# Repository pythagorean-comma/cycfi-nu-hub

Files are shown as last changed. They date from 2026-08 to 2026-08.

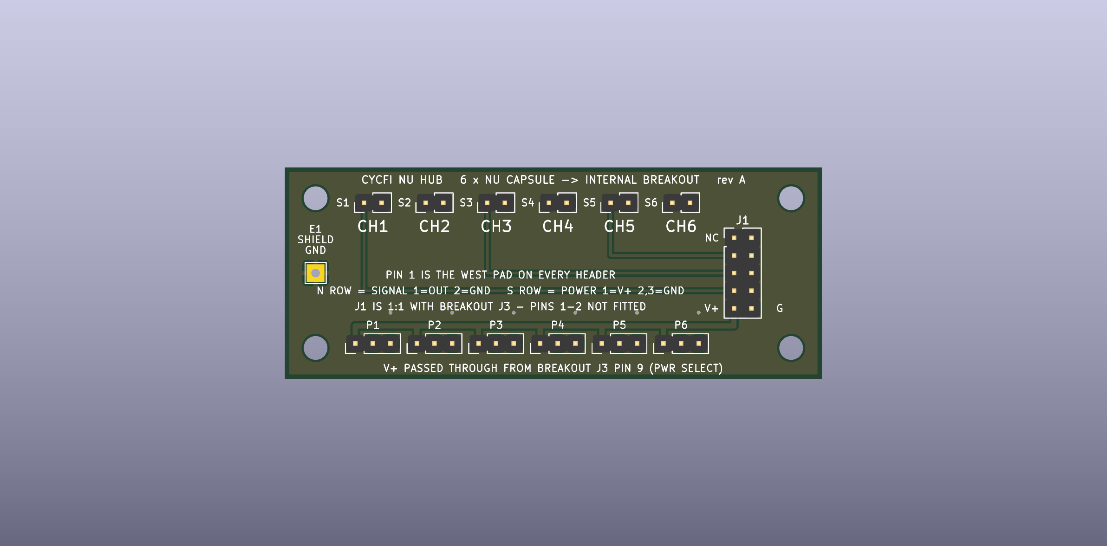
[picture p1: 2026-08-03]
fab/cycfi-nu-hub-top.png

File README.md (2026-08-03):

# Cycfi Nu Hub

A 6-channel hub board for wiring six individual **Cycfi Nu v2 capsules** into a v2.6
**Cycfi Internal Breakout** on channels 1–6.

Built against Cycfi's published Eagle sources at
<https://github.com/cycfi/nu>

61 × 24 mm, two layers, and **no components** — thirteen connectors, a
grounding pad and some copper. The capsules already decouple themselves, so
there is nothing left for this board to do but join things up correctly.

## Everything is generated

`design.py` is the single source of truth for the circuit. `gen_sch.py` draws
the schematic from it, `gen_pcb.py` places and routes the board from it, and
`verify.py` reads KiCad's own netlist back and compares it net by net.

```bash
./build.sh
```

That regenerates schematic *and* board, runs ERC, checks both against
`design.py`, runs DRC, and writes `fab/cycfi-nu-hub-pcbway.zip`, but **only
when DRC is clean**, so a board with known faults cannot reach a fab by
accident.

> **Anything changed in the KiCad GUI is destroyed by the next build.** Use the
> editor to inspect, measure and try things out; changes that should survive
> belong in the generator.

`design.py` also holds the two pin maps transcribed from Cycfi's schematics
and asserts the board against them at import, so a hub wired to the wrong
channels fails to load rather than fails on the bench.

## Requirements

**KiCad 10.x.** Install with `brew install --cask kicad`, or from
<https://www.kicad.org/download/>. The file formats written are version
specific: KiCad 9 will not open the generated schematic.

**No Python packages.** There is no virtual environment and no
`requirements.txt`, because there is nothing to install: the generators are
pure standard library. The one exception is `pcbnew`, which ships inside KiCad,
so `build.sh` runs `gen_pcb.py` under KiCad's own bundled interpreter and
everything else under `python3`. Set `PYTHON` to override which one.

`kicad.py` finds the installation. It checks `$KICAD_APP`, then
`/Applications/KiCad/KiCad.app`, then `~/Applications/KiCad/KiCad.app`, then
`kicad-cli` on `PATH`. If yours lives somewhere else:

```bash
export KICAD_APP=/path/to/KiCad.app
```

Run `python3 kicad.py` to see what it found.

## Where to read next

| | |
| --- | --- |
| [`docs/DESIGN.md`](docs/DESIGN.md) | What the board does and why, what must not be got wrong when wiring it, how it came out, and what is still open. **Start here.** |
| [`docs/CABLES.md`](docs/CABLES.md) | How to make the thirteen cables: parts, suppliers, position-by-position tables, and the continuity checks to run before anything is powered. |
| [`fab/ORDER.md`](fab/ORDER.md) | How to order it, including the four requirements that are invisible in the gerbers, and what to buy alongside it. It lives beside the gerbers rather than in `docs/` because `build.sh` copies it into the fabrication zip and `verify.py` checks the board against its figures. |
| [`docs/cycfi-sources.md`](docs/cycfi-sources.md) | What Cycfi's own files say, at a recorded commit, and how to re-extract it. Records, not specifications — where they and `docs/DESIGN.md` differ, `docs/DESIGN.md` is right. |

## Status

Generated, checked and clean: ERC 0, DRC 0 — **warnings included, not just
errors** — and the schematic matches `design.py` across 8 nets and 39 pin
connections. A fabrication package is written.

**Nothing has been made yet.** No board has been fabricated, no cable crimped
and nothing measured, so every claim in this repository comes from Cycfi's
sources and from the generators — not from a bench.

Two things to settle before ordering, both in the last section of
[`docs/DESIGN.md`](docs/DESIGN.md): Cycfi publish sources for breakout **v2.5** and this
targets **v2.6**, which is three continuity readings on J3 to confirm; and the
breakout's `PWR SELECT` jumper decides what voltage six capsules will see.

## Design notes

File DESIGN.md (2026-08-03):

# The Cycfi Nu hub

Six individual **Cycfi Nu v2 capsules** onto channels 1–6 of a v2.6 **Cycfi
Internal Breakout**, so that wiring them up is thirteen crimped connectors
instead of a bundle of flying leads into a connector that was designed for a
pre-assembled Nu Multi.

The board is 61 × 24 mm, two layers, and **carries no components at all**. It
is thirteen connectors, one solder pad, four holes and some copper. That is
not minimalism for its own sake — see [No components](#no-components).

---

## What this replaces

Cycfi's breakout expects a **Nu Multi**: a pre-built assembly of capsules that
arrives on one 2×5 ribbon. If you have six separate capsules instead, you have
twelve connectors to get to that one 2×5, and each capsule contributes two of
them, at opposite ends of its own PCB.

    six capsules                    this board              breakout
    ------------                    ----------              --------
    H2  3-pin power  -- cable -->  P1..P6                \
    H1  2-pin signal -- cable -->  S1..S6                 >-- J1 --> J3
                                                         /   2x5

## Verified, not assumed

Everything about the two mating connectors was read out of Cycfi's Eagle
sources, at a recorded commit, and is transcribed in
[`docs/cycfi-sources.md`](docs/cycfi-sources.md). The three facts the board
depends on:

1. **The capsule has two connectors, not one.** A 3-pin 2.00 mm header for
   power at one end of its PCB, pin 1 = V+ through a reverse-polarity
   Schottky — and separately a 2-pin 2.00 mm header for signal at the other
   end, pin 1 = OUT through a 10 µF coupling cap.
2. **Pins 2 *and* 3 of the power header are ground.** The capsule commits two
   of its three power positions to it.
3. **The capsule decouples itself**: 100 nF and 4.7 µF across its own supply,
   on the capsule, at the pin.

These are not comments. `design.py` holds them as `CAPSULE` and
`BREAKOUT_J3`, and `Design.check_against_cycfi()` asserts the whole board's
pin map against them at import — so a hub wired to the wrong channels fails
to load rather than fails on the bench.

That check exists because nothing else would catch it. A wrong-but-consistent
pin map is still consistent: ERC passes, the netlist comparison passes, DRC
passes, and the first symptom is six strings coming out of the wrong outputs.

## The pin map — this *is* the design

`J1` is wired **one-to-one with breakout J3**. Position *n* on the cable goes
to position *n* at both ends; nothing crosses inside it.

| J1 / J3 pin | Net | Goes to |
| --- | --- | --- |
| 1 | *CH7* | **not fitted** |
| 2 | *CH8* | **not fitted** |
| 3 | CH5 | S5 pin 1 |
| 4 | CH6 | S6 pin 1 |
| 5 | CH3 | S3 pin 1 |
| 6 | CH4 | S4 pin 1 |
| 7 | CH1 | S1 pin 1 |
| 8 | CH2 | S2 pin 1 |
| 9 | V+ | P1–P6 pin 1 |
| 10 | GND | everything |

And at the capsule end, each channel *n*:

| Header | Pin | Net | Capsule |
| --- | --- | --- | --- |
| `Pn` (1×3) | 1 | V+ | H2 pin 1 |
| | 2, 3 | GND | H2 pins 2, 3 |
| `Sn` (1×2) | 1 | CH*n* | H1 pin 1 |
| | 2 | GND | H1 pin 2 |

**Pin 1 is the west-most pad on every header on the board**, including the
2×5. One rule, printed on the silkscreen, and asserted in
`gen_pcb.check_placement()` against the real pad coordinates rather than
trusted to a rotation convention.

## What must not be got wrong

### Leave positions 1 and 2 out of the cable

They are CH7 and CH8, and those nets are **shared with J4 pins 7–8** — the
breakout's second Nu Multi input. Driving them from here contends with
anything plugged in there.

### Reversal is harmless, and that is why

A 2×5 rotated in its own plane maps pin *n* to pin **11 − *n***. So a cable
plugged in backwards puts the two *empty* positions onto pins 10 and 9 — GND
and V+ — and the hub receives no supply at all. The capsules stay dark, the
hub's own V+ and GND land on CH8 and CH7 where nothing is driving them hard,
and nothing is damaged.

This is worth stating because it is the reason the board has a **plain,
unshrouded** 2×5. Shrouding at 2.00 mm means committing to a keyed family —
JST PHD or Hirose DF11 are the stock options whose pin numbering matches
Cycfi's — and that puts a *different crimp terminal at each end of the same
cable*, since the breakout end still has to mate with a plain header. Paying
that to protect against a failure whose entire consequence is "it does not
turn on" is a bad trade.

If the cable ever works loose under vibration, the answer is a tie or a dab of
hot glue, not a respin.

### The two 2.00 mm systems are not interchangeable

Everything here mates with **2.00 mm female crimp housings on 0.50 mm square
posts**. Pick one connector family and stay in it for the whole loom, so there
is one terminal and one tool. This is not the same as JST PH, which is also
2.00 mm and will not fit.

## No components

`design.py` states this as `NO_COMPONENTS` and enforces it in
`Design.check_no_components()`, which rejects any part that is not a
connector, a mounting hole or the grounding pad.

The previous revision of this board had six decoupling capacitors on it. They
were doing nothing, and the reason is worth keeping: **every Nu capsule
already carries 100 nF and 4.7 µF across its own supply pins, at the pin, on
the capsule PCB.** A capacitor on the hub sits at the far end of a cable from
every load it could serve. It is not decoupling; it is a part that measures as
wire.

There is nothing to protect either. Pin 1 of the capsule's power header goes
through a Schottky *on the capsule*, so reverse polarity is handled where it
matters, and — per above — a reversed 2×5 delivers no supply rather than the
wrong one.

So the board permits, permanently: connectors, mounting holes, one grounding
pad. If a resistor or capacitor appears in the parts list, either the circuit
has genuinely changed or something was added on instinct, and the build says
so.

## Grounding

GND is poured on **both** layers. On a two-layer board that is mostly air the
copper is free, and what it buys is a return directly under every signal trace
and a reference plane between the six of them. Against a Nu's low-impedance
op-amp output that is worth little — but it is worth nothing against it
either, and it costs the same to fabricate. Six stitching vias tie the pours
together, on top of the nineteen through-hole GND pads that already do.

**E1** is a 2.0 × 2.0 mm pad on a 1.0 mm hole, on GND, for a bridge earth or a
cavity-shielding tail. It is optional. Fitting the pad does not commit you to
using it, and in an all-active instrument some builders deliberately leave the
bridge floating — that is the path that puts the player at mains potential if
something upstream fails. Use it for foil and decide about the bridge
separately.

The objection to landing bridge earth here is that it makes the hub the ground
meeting point, so string-borne hum shares the single GND wire in the cable
with six signal returns. At microamps through tens of milliohms that is
nanovolts. It is not a real mechanism at these levels.

**The four mounting holes are unplated and off the ground net**, deliberately.
A hub screwed into a shielded cavity with metal screws and plated holes would
bond the audio ground to the foil through the mounting hardware, in parallel
with the cable — a second ground path, which is the loop the single-point pad
exists to avoid.

## How the board came out

A 61 × 24 mm strip. Signal headers along the north edge, power headers along
the south, the 2×5 at the east end, six channel columns on a 7 mm pitch with
**CH1 (low E) at the west**, so reading the board left to right reads the
strings low to high. The two cable bundles leave on opposite edges.

`verify.check_string_order()` reads the string order back off the built
copper. Nothing electrical would notice it being wrong.

### The one hard part: reaching the far row of J1

The 2×5's pads are 1.35 mm on a 2.00 mm pitch. The clear gap between two of
them is **0.65 mm**, and a 0.30 mm track with 0.25 mm either side needs
**0.80 mm**. Nothing can be routed between the pads of a 2.00 mm header, so
the far row cannot be reached from the near side at all. `rules.py` asserts
this rather than leaving it as folklore, because the whole layout is shaped by
it.

So the near row — J1's odd pins, CH5/CH3/CH1 — is reached directly from the
west on F.Cu, and the far row — even pins, CH6/CH4/CH2 — goes **north of the
signal headers on B.Cu, east above the whole row, down the outside of the
connector, and back in from the east**, where nothing is in the way. Three
concentric L-shaped paths around the north-east corner.

Two placement decisions make that fan-in planar, and both are the opposite of
what looks natural:

- **CH1 at the west, J1 at the east.** The connector puts CH1/CH2 on its
  southern pair and CH5/CH6 on its northern one, so a channel's target *y*
  falls as its number falls. With CH1 furthest from the connector, the
  westmost channel wants the deepest lane, and every drop clears every lane
  already laid. Mirror the board and all three cross.
- **The detour goes north of the signal headers, not between them and J1.**
  Put the lanes south of the header row and the drops cross them; put them
  north and the headers sit on the boundary, where the three paths nest.

I got the second one wrong twice before checking it as a planarity problem
rather than by eye.

### Everything else

- The power row has no gaps: six 1×3 footprints on a 7 mm pitch leave 0.78 mm
  between silk outlines, which is why nothing crosses it and why the power
  designators are printed above the row instead of beside it.
- The two eastern mounting holes set the board width. Their courtyards are
  6 mm across because they have to clear a screw head, and they have to sit
  clear of the three descents to J1's far row.
- V+ runs as one bus on F.Cu between J1's bottom pair and the power row.
  0.60 mm, which is not about current — six capsules draw single-figure
  milliamps between them — but about keeping the run stiff and inspectable.
- The build gates on DRC **warnings as well as errors**. It did not at first,
  and asking only for errors hid twenty-seven violations of this project's own
  rules: every legend was under the minimum silk text height written into the
  `.kicad_pro`, and six designators overlapped their own footprint outlines.
  None of it would have scrapped a board and all of it would have reached one.
  `rules.MIN_SILK_TEXT` is now the single place that height is declared, so
  the generator and the checker cannot disagree about it again.

## Still open

**The breakout revision.** Cycfi's published sources are silkscreened
*INTERNAL BREAKOUT V2.5* and this hub targets **v2.6**. Nothing the hub
touches is known to have changed, and Cycfi have not published 2.6 sources —
but it has not been *checked*, and it is one continuity test to settle. Before
building the cable, meter J3 on the actual breakout: **pin 9 to V+, pin 10 to
ground, pin 7 to channel 1.** If those three are right, the whole table is.

**Which rail the PWR SELECT jumper is on.** J14 on the breakout selects
whether V+ is the unregulated input or the LP2985 output. The hub passes
through whatever it is, so the board does not care — but the capsules do.
Confirm the jumper is where you want it before six capsules see it.

**Nothing has been fabricated yet.** No board has been made, no cable crimped
and nothing measured. Every claim here is from the sources and the generators.

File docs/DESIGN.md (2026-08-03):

# The Cycfi Nu hub

Six individual **Cycfi Nu v2 capsules** onto channels 1–6 of a v2.6 **Cycfi
Internal Breakout**, so that wiring them up is thirteen crimped connectors
instead of a bundle of flying leads into a connector that was designed for a
pre-assembled Nu Multi.

The board is 61 × 24 mm, two layers, and **carries no components at all**. It
is thirteen connectors, one solder pad, four holes and some copper. That is
not minimalism for its own sake — see [No components](#no-components).

---

## What this replaces

Cycfi's breakout expects a **Nu Multi**: a pre-built assembly of capsules that
arrives on one 2×5 ribbon. If you have six separate capsules instead, you have
twelve connectors to get to that one 2×5, and each capsule contributes two of
them, at opposite ends of its own PCB.

    six capsules                    this board              breakout
    ------------                    ----------              --------
    H2  3-pin power  -- cable -->  P1..P6                \
    H1  2-pin signal -- cable -->  S1..S6                 >-- J1 --> J3
                                                         /   2x5

## Verified, not assumed

Everything about the two mating connectors was read out of Cycfi's Eagle
sources, at a recorded commit, and is transcribed in
[`cycfi-sources.md`](cycfi-sources.md). The three facts the board
depends on:

1. **The capsule has two connectors, not one.** A 3-pin 2.00 mm header for
   power at one end of its PCB, pin 1 = V+ through a reverse-polarity
   Schottky — and separately a 2-pin 2.00 mm header for signal at the other
   end, pin 1 = OUT through a 10 µF coupling cap.
2. **Pins 2 *and* 3 of the power header are ground.** The capsule commits two
   of its three power positions to it.
3. **The capsule decouples itself**: 100 nF and 4.7 µF across its own supply,
   on the capsule, at the pin.

These are not comments. `design.py` holds them as `CAPSULE` and
`BREAKOUT_J3`, and `Design.check_against_cycfi()` asserts the whole board's
pin map against them at import — so a hub wired to the wrong channels fails
to load rather than fails on the bench.

That check exists because nothing else would catch it. A wrong-but-consistent
pin map is still consistent: ERC passes, the netlist comparison passes, DRC
passes, and the first symptom is six strings coming out of the wrong outputs.

## The pin map — this *is* the design

`J1` is wired **one-to-one with breakout J3**. Position *n* on the cable goes
to position *n* at both ends; nothing crosses inside it.

| J1 / J3 pin | Net | Goes to |
| --- | --- | --- |
| 1 | *CH7* | **not fitted** |
| 2 | *CH8* | **not fitted** |
| 3 | CH5 | S5 pin 1 |
| 4 | CH6 | S6 pin 1 |
| 5 | CH3 | S3 pin 1 |
| 6 | CH4 | S4 pin 1 |
| 7 | CH1 | S1 pin 1 |
| 8 | CH2 | S2 pin 1 |
| 9 | V+ | P1–P6 pin 1 |
| 10 | GND | everything |

And at the capsule end, each channel *n*:

| Header | Pin | Net | Capsule |
| --- | --- | --- | --- |
| `Pn` (1×3) | 1 | V+ | H2 pin 1 |
| | 2, 3 | GND | H2 pins 2, 3 |
| `Sn` (1×2) | 1 | CH*n* | H1 pin 1 |
| | 2 | GND | H1 pin 2 |

**Pin 1 is the west-most pad on every header on the board**, including the
2×5. One rule, printed on the silkscreen, and asserted in
`gen_pcb.check_placement()` against the real pad coordinates rather than
trusted to a rotation convention.

## What must not be got wrong

### Leave positions 1 and 2 out of the cable

They are CH7 and CH8, and those nets are **shared with J4 pins 7–8** — the
breakout's second Nu Multi input. Driving them from here contends with
anything plugged in there.

### Reversal is harmless, and that is why

A 2×5 rotated in its own plane maps pin *n* to pin **11 − *n***. So a cable
plugged in backwards puts the two *empty* positions onto pins 10 and 9 — GND
and V+ — and the hub receives no supply at all. The capsules stay dark, the
hub's own V+ and GND land on CH8 and CH7 where nothing is driving them hard,
and nothing is damaged.

This is worth stating because it is the reason the board has a **plain,
unshrouded** 2×5. Shrouding at 2.00 mm means committing to a keyed family —
JST PHD or Hirose DF11 are the stock options whose pin numbering matches
Cycfi's — and that puts a *different crimp terminal at each end of the same
cable*, since the breakout end still has to mate with a plain header. Paying
that to protect against a failure whose entire consequence is "it does not
turn on" is a bad trade.

If the cable ever works loose under vibration, the answer is a tie or a dab of
hot glue, not a respin.

### The two 2.00 mm systems are not interchangeable

Everything here mates with **2.00 mm female crimp housings on 0.50 mm square
posts**. Pick one connector family and stay in it for the whole loom, so there
is one terminal and one tool. This is not the same as JST PH, which is also
2.00 mm and will not fit.

## No components

`design.py` states this as `NO_COMPONENTS` and enforces it in
`Design.check_no_components()`, which rejects any part that is not a
connector, a mounting hole or the grounding pad.

The previous revision of this board had six decoupling capacitors on it. They
were doing nothing, and the reason is worth keeping: **every Nu capsule
already carries 100 nF and 4.7 µF across its own supply pins, at the pin, on
the capsule PCB.** A capacitor on the hub sits at the far end of a cable from
every load it could serve. It is not decoupling; it is a part that measures as
wire.

There is nothing to protect either. Pin 1 of the capsule's power header goes
through a Schottky *on the capsule*, so reverse polarity is handled where it
matters, and — per above — a reversed 2×5 delivers no supply rather than the
wrong one.

So the board permits, permanently: connectors, mounting holes, one grounding
pad. If a resistor or capacitor appears in the parts list, either the circuit
has genuinely changed or something was added on instinct, and the build says
so.

## Grounding

GND is poured on **both** layers. On a two-layer board that is mostly air the
copper is free, and what it buys is a return directly under every signal trace
and a reference plane between the six of them. Against a Nu's low-impedance
op-amp output that is worth little — but it is worth nothing against it
either, and it costs the same to fabricate. Six stitching vias tie the pours
together, on top of the nineteen through-hole GND pads that already do.

### E1

A 2.0 × 2.0 mm pad on a 1.0 mm hole, on GND, silkscreened SHIELD / GND.

**It is not a circuit feature.** GND is already poured across both layers, so
E1 adds no connection — it is simply the one place where the mask is open and
the pad is big enough to solder a wire to. That is its whole point: without
it, somebody eventually abrades the pour or hangs a tail off an occupied
connector pin. It costs one hole and no board area, since the west margin it
sits in is set by the mounting holes and would be empty anyway.

It has three jobs, and only the first is designed in.

**The trunk cable's screen.** [`CABLES.md`](CABLES.md) specifies screened cable
for the hub → breakout run with the screen grounded **at one end only**, so it
cannot become a second ground path in parallel with the GND conductor in
position 10. E1 is that end. Use screened cable and the pad stops being
optional — there is nowhere else for the drain to go.

**Cavity foil.** Shielding does nothing unless it is tied to circuit ground,
and left floating it can couple slightly worse than none. But foil carries
only displacement currents, so it can be grounded anywhere on the system —
the hub is convenient, not required.

**A bridge earth, distantly.** Weaker here than the convention suggests. The
mechanism it defends against — the player's body coupling mains hum into a
high-impedance circuit — is largely handled already by every Nu output being
an op-amp behind a 10 µF capacitor into low-impedance cabling. Against that,
it is the connection that puts the player at circuit ground through the
strings, which in an upstream fault is a path toward mains potential, and it
conventionally belongs at the system's main ground point rather than on a leaf
board at the far end of a cable. Fitting the pad does not commit you to using
it for this, and the silkscreen deliberately does not say BRIDGE.

One objection that does *not* stand up: that landing a tail here makes the hub
a ground meeting point, so its return shares the single GND wire in the cable
with six signal returns. At microamps through tens of milliohms that is
nanovolts. It is not a real mechanism at these levels.

**The four mounting holes are unplated and off the ground net**, deliberately.
A hub screwed into a shielded cavity with metal screws and plated holes would
bond the audio ground to the foil through the mounting hardware, in parallel
with the cable — a second ground path, which is the loop the single-point pad
exists to avoid.

## How the board came out

A 61 × 24 mm strip. Signal headers along the north edge, power headers along
the south, the 2×5 at the east end, six channel columns on a 7 mm pitch with
**CH1 (low E) at the west**, so reading the board left to right reads the
strings low to high. The two cable bundles leave on opposite edges.

`verify.check_string_order()` reads the string order back off the built
copper. Nothing electrical would notice it being wrong.

### The one hard part: reaching the far row of J1

The 2×5's pads are 1.35 mm on a 2.00 mm pitch. The clear gap between two of
them is **0.65 mm**, and a 0.30 mm track with 0.25 mm either side needs
**0.80 mm**. Nothing can be routed between the pads of a 2.00 mm header, so
the far row cannot be reached from the near side at all. `rules.py` asserts
this rather than leaving it as folklore, because the whole layout is shaped by
it.

So the near row — J1's odd pins, CH5/CH3/CH1 — is reached directly from the
west on F.Cu, and the far row — even pins, CH6/CH4/CH2 — goes **north of the
signal headers on B.Cu, east above the whole row, down the outside of the
connector, and back in from the east**, where nothing is in the way. Three
concentric L-shaped paths around the north-east corner.

Two placement decisions make that fan-in planar, and both are the opposite of
what looks natural:

- **CH1 at the west, J1 at the east.** The connector puts CH1/CH2 on its
  southern pair and CH5/CH6 on its northern one, so a channel's target *y*
  falls as its number falls. With CH1 furthest from the connector, the
  westmost channel wants the deepest lane, and every drop clears every lane
  already laid. Mirror the board and all three cross.
- **The detour goes north of the signal headers, not between them and J1.**
  Put the lanes south of the header row and the drops cross them; put them
  north and the headers sit on the boundary, where the three paths nest.

I got the second one wrong twice before checking it as a planarity problem
rather than by eye.

### Everything else

- The power row has no gaps: six 1×3 footprints on a 7 mm pitch leave 0.78 mm
  between silk outlines, which is why nothing crosses it and why the power
  designators are printed above the row instead of beside it.
- The two eastern mounting holes set the board width. Their courtyards are
  6 mm across because they have to clear a screw head, and they have to sit
  clear of the three descents to J1's far row.
- V+ runs as one bus on F.Cu between J1's bottom pair and the power row.
  0.60 mm, which is not about current — six capsules draw single-figure
  milliamps between them — but about keeping the run stiff and inspectable.
- The build gates on DRC **warnings as well as errors**. It did not at first,
  and asking only for errors hid twenty-seven violations of this project's own
  rules: every legend was under the minimum silk text height written into the
  `.kicad_pro`, and six designators overlapped their own footprint outlines.
  None of it would have scrapped a board and all of it would have reached one.
  `rules.MIN_SILK_TEXT` is now the single place that height is declared, so
  the generator and the checker cannot disagree about it again.

## Still open

**The breakout revision — mostly resolved.** Cycfi's published *sources* are
silkscreened *INTERNAL BREAKOUT V2.5* and this hub targets **v2.6**. They have
not published 2.6 Eagle files, but they do publish a
[v2.6.1 datasheet](https://www.cycfi.com/assets/Internal-Breakout-2.6.pdf),
and its "Nu Multi Inputs Ch 1-8" diagram gives the two rows as

    Ch8  Ch6  Ch4  Ch2  Gnd
    Ch7  Ch5  Ch3  Ch1  10v

which pairs **exactly** as the v2.5 sources do — CH7/CH8, CH5/CH6, CH3/CH4,
CH1/CH2, supply/ground. The pin map this board is built on survives the
revision.

What a printed pin map cannot tell you is which physical end of the connector
is position 1, and the v2.6 board is a different shape from the v2.5 one
(Cycfi list it as 27 × 38 mm against the 50 × 35 mm in the Eagle files), so
the connector may well sit differently. That is still one meter reading to
settle: **pin 9 to the supply rail, pin 10 to ground, pin 7 to channel 1.**
[`CABLES.md`](CABLES.md) has it as a numbered step.

**What voltage the capsules will see.** On v2.5 the Nu Multi input's supply
pin is a net called V+, fed from `J14`, a jumper silkscreened `PWR SELECT`
that chooses between the unregulated input and the LP2985 output. On v2.6.1
the same pin is labelled simply **10V**. The hub passes through whatever it
is, so the board does not care — but six capsules do. Measure it at the hub
with no capsules connected before fitting any.

**Nothing has been fabricated yet.** No board has been made, no cable crimped
and nothing measured. Every claim here is from the sources and the generators.

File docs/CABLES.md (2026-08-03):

# Making the cables

Thirteen cables connect six Nu capsules to the hub, and the hub to the
Internal Breakout. None of them is difficult. One of them — the capsule power
cable — has a way of going wrong that shorts the supply, and it is the exact
mistake that Cycfi's own cable guide will lead you into if you follow it
literally. That is [warning 1](#1-position-1-is-not-ground) below, and it is
the reason this document exists rather than a link.

Read Cycfi's guide for **technique**:
<https://www.cycfi.com/how-to-make-and-repair-pin-header-cables/>. It is
better than anything written here on how to actually hold the tool. Read this
for **which wire goes where**.

---

## What you are building

| # | Cable | Ends | Positions used | Qty |
| --- | --- | --- | --- | --- |
| 1 | Capsule power | 3-way ↔ 3-way | 3 of 3 | 6 |
| 2 | Capsule signal | 2-way ↔ 2-way | 2 of 2 | 6 |
| 3 | Hub → breakout | 2×5 ↔ 2×5 | **8 of 10** | 1 |

Two cables per capsule and not one, because the capsule has two connectors: a
3-pin power header at one end of its PCB and a 2-pin signal header at the
other. The hub mirrors that — `P1`–`P6` along its south edge, `S1`–`S6` along
its north edge, same channel in the same column.

---

## Two warnings before you buy anything

### 1. Position 1 is not ground

Cycfi's guide says:

> "Make sure you insert all GND wires (black) into position 1, indicated by a
> small molded triangle in the crimp housing"

**That is for a different cable. Do not do it here.** On the Nu capsule's own
connectors, read out of Cycfi's Eagle schematic:

| Capsule connector | Position 1 is |
| --- | --- |
| H2, 3-pin power | **V+**, through a Schottky diode on the capsule |
| H1, 2-pin signal | **OUT**, through the 10 µF coupling capacitor |

Ground is on positions 2 and 3 of the power header, and position 2 of the
signal header. The hub mirrors the capsule exactly, so the same is true at
both ends of every capsule cable.

Get this backwards on a power cable and you connect the supply rail to the
capsule's ground: the Schottky blocks the reverse feed so the capsule never
powers up, and V+ sits shorted to ground through the capsule's ground pour.
The breakout's regulator will current-limit or shut down. Nothing here is
subtle enough to survive by luck — **check the triangle against the tables
below before you insert a single contact.**

The molded-triangle convention itself is right and worth using: the triangle
marks position 1 on the housing. On the hub, **position 1 is always the
west-most pad**, which is printed on the silkscreen.

### 2. Two positions on the 2×5 stay empty

Positions **1 and 2** of the hub → breakout cable are not crimped, at either
end. They are the breakout's CH7 and CH8, and those two nets are shared with
J4 pins 7–8 — the second Nu Multi input. Filling them would contend with
anything plugged in there.

Leaving them empty is also what makes a reversed cable harmless: a 2×5
rotated in its own plane maps position *n* to position 11 − *n*, so the two
empty positions land on V+ and GND and the hub receives no supply at all.
A backwards cable is a dead cable, not a dead capsule.

---

## Tools

| Tool | Notes |
| --- | --- |
| **Engineer PA-09 crimping pliers** | Cycfi's choice, and the right one. Four dies: 1.0 / 1.4 / 1.6 / 1.9 mm. [Amazon](https://www.amazon.com/ENGINEER-AWG32-AWG20-Connectors-Oil-Resistant-PA-09/dp/B002AVVO7K) · [The Pi Hut](https://thepihut.com/products/universal-micro-crimping-pliers-1-0-to-1-9mm-size-contacts) · [TME](https://www.tme.com/us/en-us/details/fut.pa-09/crimping-tools-for-terminals/engineer/pa-09/) |
| Wire strippers | Something that will do 28–30 AWG cleanly |
| Flush cutters | |
| Fine tweezers | For inserting contacts and for extraction during repair |
| **Multimeter with continuity beep** | Not optional. See [Verify](#verify-before-you-plug-anything-in). |
| Heat gun or lighter | |

**On the die size.** Cycfi write *"Use the 1/4″ cavity size for the 2 mm crimp
terminals."* The PA-09 has no 1/4-inch die — its four dies are metric, marked
1.0, 1.4, 1.6 and 1.9 mm — so read that as the **1.4 mm** die. Do not take my
word for it either: crimp one contact, look at it under magnification, and
pull on the wire hard. The wire should not come out and the insulation grip
should be closed on the jacket, not on bare conductor. Adjust a die size
either way if it is not right. You will make 76 of these; spend the first
three getting the setting right.

If you go the Hirose DF11 route for the 2×5 (below), Hirose's own hand tool is
[DF11-TA2428HC](https://www.newark.com/hirose-hrs/df11-ta2428hc/hand-crimp-tool-28-24awg-skt-contact/dp/49P5012).
It is far more expensive than the PA-09 and only worth it if you are making
these regularly.

---

## Parts

### Single-row housings and contacts — capsule cables

These are Hirose's 2.00 mm single-row crimp system, the same parts Cycfi
specify in their guide.

| Part | What | Qty needed | Where |
| --- | --- | --- | --- |
| **A4B-3S-2C** | 3-way housing, 2.00 mm | 12 | [DigiKey H2012-ND](https://www.digikey.com/en/products/detail/hirose-electric-co-ltd/A4B-3S-2C/141219) · [RS 7644761](https://uk.rs-online.com/web/p/wire-housings-plugs/7644761) |
| **A4B-2S-2C** | 2-way housing, 2.00 mm | 12 | [DigiKey 141216](https://www.digikey.com/en/products/detail/hirose-electric-co-ltd/A4B-2S-2C/141216) · [Mouser](https://www.mouser.com/ProductDetail/Hirose-Connector/A4B-2S-2C) |
| **A3B-2630SCC** | Crimp socket, gold, 26–30 AWG | 60 → **buy 90** | [Mouser](https://www.mouser.com/ProductDetail/Hirose-Connector/A3B-2630SCC) |

Twelve of each housing, not six: every cable has one at each end.

### The 2×5 — the one part I could not verify

**Both ends of this cable are the same interface, and that is deliberate.** The
hub's `J1` and the breakout's `J3` are both plain, unshrouded 2×5 headers on a
2.00 mm grid with 0.5 mm square posts — Cycfi's is the `2X5` package from their
`headers(2mm)` Eagle library, the hub's is KiCad's
`PinHeader_2x05_P2.00mm_Vertical`. The PCB hole sizes differ slightly, 0.75 mm
against 0.80 mm, but that is the board, not the pin: the same commodity header
strip fits both, and both number their pins in pairs across the rows, which is
what lets the cable be wired one-to-one.

Three consequences, and they are the whole reason to keep it that way:

- **One test-fit qualifies both ends.** Whatever you prove on the hub is
  equally true of the breakout, because it is the same part.
- **Whichever housing wins is used at both ends.** One housing, one contact,
  one crimp setting for the trunk, and the two ends are interchangeable.
- **If the first choice fails, nothing is stranded** except the sample. Swap
  routes and you are still symmetric.

It is tempting to fix this by fitting a keyed, shrouded connector at the hub —
a Hirose `DF11-10DP-2DSA` in place of the plain header. Don't. It buys
certainty about the end that was never in doubt, still leaves the breakout end
to be tested, and pays for it by making the cable asymmetric and committing
the hub to one connector family for good. The retention it adds is
half a fix that a cable tie does properly at both ends for nothing.

What you need, then, is a 10-way (2×5) socket housing that fits bare 0.5 mm
square posts. **I could not confirm a specific part for this from the
manufacturers' documentation, and I am not going to pretend otherwise.** Two
routes, and whichever you pick, **buy one housing and a few contacts first and
test-fit them on the hub** — that sample decides the whole trunk, so it is
worth having in your hand before the rest of the order goes in. Test on the
hub rather than the breakout: same interface, and you are not levering an
unproven connector onto Cycfi's board.

| Route | Parts | Trade-off |
| --- | --- | --- |
| **Hirose DF11** | [DF11-10DS-2C](https://www.futureelectronics.com/p/interconnect--pin-and-socket-connectors--socket-plug-wire-mount/df11-10ds-2c-hirose-electric-4329116) housing + [DF11-2428SCA](https://www.digikey.com/en/products/detail/hirose-electric-co-ltd/df11-2428sca/150215) contacts, 24–28 AWG gold | Better made, and there is real precedent: Cycfi's own guide puts Hirose **A4B** housings on the capsule's H1/H2, which are *generic* 2 mm headers — so a Hirose 2 mm socket is known to mate with a bare 2 mm post. Against it: that precedent is single-row, where A4B has no shroud in the first place. DF11's socket is designed against Hirose's own shrouded header, and I never found the post cross-section that decides it. Different contact from the capsule cables, so a second crimp setting. |
| **Generic 2.00 mm "Dupont"** | 2×5 10-way 2.0 mm socket housing + 2.0 mm crimp terminals | Explicitly made for bare square-post headers, so fit is correct *by design* rather than by luck — this is the technically conservative choice, not the cheap one. Cycfi's own guide calls these "2 mm Dupont" parts. Variable quality; buy from a supplier you have used before. |

A third possibility if you want **one contact type for the entire build**: two
`A4B-5S-2C` five-way housings side by side. The A4B housing body is 2.0 mm
wide and the row pitch is 2.0 mm, so two of them abutted should land on both
rows, and you would use A3B-2630SCC throughout. I have not tested this and the
housings would need bonding together — treat it as an experiment, not a plan.

#### Qualifying the sample

Ten minutes, and it settles the whole trunk. Two of these failure modes pass a
plain continuity check, which is why the wiggle and the re-insertion count
matter more than the beep.

1. Push the **bare housing, no contacts** onto `J1`. It should seat fully and
   square without forcing.
2. Crimp one contact, insert it, check continuity — then **press the cable
   sideways.** Intermittence here is the answer on its own.
3. Mate and unmate **ten times**, then check retention again. If it has gone
   slack, the contact beams are taking a permanent set: the connector works on
   the bench and degrades in the instrument.
4. Pull that contact back out and look at the beams under magnification.
   Splayed or flattened is a fail.
5. Confirm the moulded position-1 triangle lands on the pin you expect. A
   female housing seen from its mating face numbers the *mirror* of the male
   header seen from above, and this is where people get it backwards.

If it passes but retention feels marginal, that is a cable tie or a dab of
hot-melt at each end, not a different connector.

### Wire

Cycfi use 28–30 AWG shielded and link
[UL2547 28 AWG multi-core shielded on AliExpress](https://www.aliexpress.com/w/wholesale-UL2547-28AWG-shielded-cable.html).
Same family here:

| Cable | Stock | Why |
| --- | --- | --- |
| Capsule power ×6 | **2-core + shield, 28 AWG** | Red core = V+, black core = GND, shield = the *second* ground. See below. |
| Capsule signal ×6 | **1-core + shield, 28 AWG** | Core = OUT, shield = GND. A screened core is exactly right for an audio run. 2-core + shield works too — leave one core cut back. |
| Hub → breakout ×1 | **8-core + shield, 28 AWG** | 6 channels + V+ + GND on the cores; the shield lands on the hub's `E1` pad. |

If 8-core is hard to source, two 4-core shielded cables run side by side do the
same job.

Measure the runs in the instrument before cutting, then add 20%. A cable that
is 10 mm short is scrap.

### Heat-shrink

Cycfi's sizes, and they are the right ones:

- **3/64″ or 1/16″** — over each twisted shield tail, before crimping
- **1/8″** — over the cable jacket where it enters the housing

### Colour convention

Cycfi's, extended for the trunk:

| Colour | Net |
| --- | --- |
| Red | V+ |
| Black | GND |
| White | Signal (single-channel cables) |
| 6 distinct colours | CH1…CH6 in the hub → breakout cable |

Write down which trunk colour is which channel **before** you crimp, and keep
that note with the instrument. Channel order is not recoverable by looking at
the finished cable.

---

## Cable 1 — capsule power, ×6

3-way at both ends. Both ends are wired **identically**: position 1 to
position 1, and so on. Nothing crosses.

| Position | Net | Conductor | Capsule (H2) | Hub (`P1`–`P6`) |
| --- | --- | --- | --- | --- |
| **1** | **V+** | red core | V+ via Schottky | pin 1, west-most |
| 2 | GND | black core | GND | pin 2 |
| 3 | GND | **shield** | GND | pin 3 |

The capsule commits two of its three power positions to ground, so carry both.
Cycfi's trick is what makes this easy with a 2-core-plus-shield cable: split
the shield braid into two halves and twist each into its own tail. Here you
only need one shield tail per end — the black core covers position 2 and the
shield covers position 3.

Two independent ground conductors is not belt-and-braces for its own sake: it
halves the return resistance and it fills the housing, which is worth as much
for retention as it is electrically.

## Cable 2 — capsule signal, ×6

2-way at both ends, wired straight through.

| Position | Net | Conductor | Capsule (H1) | Hub (`S1`–`S6`) |
| --- | --- | --- | --- | --- |
| **1** | **OUT** | white core | output via 10 µF cap | pin 1, west-most |
| 2 | GND | shield | GND | pin 2 |

Keep these six cables away from the power bundle where you can. It costs
nothing to route them along opposite sides of the cavity, and the hub is laid
out so the two bundles leave on opposite edges for exactly that reason.

## Cable 3 — hub → breakout, ×1

2×5 at both ends, **8 of 10 positions crimped**, wired straight through:
position *n* to position *n*.

| Position | Net | Conductor | | Position | Net | Conductor |
| --- | --- | --- | --- | --- | --- | --- |
| **1** | *CH7* | **empty** | | **2** | *CH8* | **empty** |
| 3 | CH5 | colour 5 | | 4 | CH6 | colour 6 |
| 5 | CH3 | colour 3 | | 6 | CH4 | colour 4 |
| 7 | CH1 | colour 1 | | 8 | CH2 | colour 2 |
| 9 | **V+** | red | | 10 | **GND** | black |

Note the channel order: the pairs run CH7/CH8, CH5/CH6, CH3/CH4, CH1/CH2 —
**descending**, with CH1 nearest the supply end. That is Cycfi's numbering, not
a mistake, and it is why the hub places CH1 furthest from its own connector.

**The shield does not go in the housing.** Solder it to the hub's `E1` pad and
leave it unconnected at the breakout end. Grounding a screen at one end only
is what stops it becoming a second ground path in parallel with position 10.
`E1` is the 2.0 mm square pad on the west edge, silkscreened SHIELD / GND;
it is on GND and it will take the shield tail and a cavity-foil wire together.

---

## Crimping

Cycfi's procedure, which works:

1. **Strip.** Hold the unstripped wire against the contact to judge the strip
   length. The contact has two pairs of tabs — the inner pair grips bare
   conductor, the outer pair grips the jacket. Both should close on the right
   thing.
2. **Prepare shield tails.** Gather the braid to one side, twist it tight, and
   slide 3/64″ or 1/16″ heat-shrink over it, leaving bare wire proud for the
   crimp. An untwisted shield tail will splay out inside the housing and short
   to its neighbour.
3. **Crimp**, 1.4 mm die (see above). Conductor tabs first, then jacket tabs.
4. **Pull-test every one.** A firm tug on the wire. Discard anything that
   moves — this is why you bought 50% spares.
5. **Insert** into the housing until it clicks. Tug the wire again: a properly
   seated contact will not back out.
6. **Check against the table** for that cable, using the molded triangle as
   position 1, *before* you heat-shrink anything.
7. **Sleeve** the jacket entry with 1/8″ heat-shrink, protruding slightly into
   the wires so the bundle cannot flex right at the housing.

---

## Verify before you plug anything in

Every one of these takes under a minute and one of them will eventually save
you six capsules. Do all of them.

### Step 1 — each cable, on the bench, nothing connected

- **Continuity, position *n* to position *n*** at the two ends. All of them.
- **No continuity between any two adjacent positions.** This is the one that
  catches a splayed shield tail or a whisker.
- On the trunk cable, confirm **positions 1 and 2 are empty at both ends** and
  that nothing beeps to them.

### Step 2 — the hub, before power

With the trunk cable plugged into the hub but **not** into the breakout:

- **V+ to GND at the far end of the trunk: must be open.** If this beeps, stop
  — something is shorted and it will land straight across the breakout's
  regulator.
- Position 9 at the breakout end to pin 1 of every `P1`–`P6` on the hub:
  should beep, all six.
- Position 10 to pin 2 and pin 3 of every `P` header, and pin 2 of every `S`
  header: should beep.
- Position 7 to `S1` pin 1 (CH1). Position 8 to `S2` pin 1. Then check the
  other four against the table above.

### Step 3 — power, with no capsules connected

Plug the trunk into the breakout. Power the breakout **with the capsule cables
unplugged** and measure V+ to GND at each of `P1`–`P6` on the hub.

All six should read the breakout's Nu Multi rail. On the v2.6.1 breakout that
pin is silkscreened **10V**; on the published v2.5 sources it is a net called
V+ fed from the `PWR SELECT` jumper (`J14`), which chooses between the
unregulated input and the LP2985 output. Whichever your board does, **confirm
the number is what you expect before six capsules see it.**

### Step 4 — one capsule

Connect a single capsule, power up, confirm it works, then do the rest. If
something is wrong with your understanding of the pinout, it is much better to
find out with one capsule connected than six.

---

## Repair

Contacts can be removed and reused. Cycfi's method:

1. Use tweezers to bend the plastic crimp lock in the housing slightly
   outward. Gently — it snaps off if you overdo it.
2. Push the contact out from the mating face until you can pull it clear.
3. Press the lock lightly back to its original position.

To extend a wire that has broken too short to re-crimp: strip both the stub
and a length of 26–28 AWG, twist and solder the joint, cover it with
heat-shrink, then measure, strip and crimp as usual.

---

## Where these numbers came from

The capsule pinouts and the breakout J3 pinout were read out of Cycfi's Eagle
sources at a recorded commit — see [`cycfi-sources.md`](cycfi-sources.md)
for the extraction and [`DESIGN.md`](DESIGN.md) for what the board does with
them. `design.py` asserts the hub's pin map against those tables at import, so
the tables in this document and the copper on the board cannot disagree
without the build failing.

The one thing not derived from a file is which physical end of the breakout's
`J3` is position 1. Cycfi's v2.6.1 datasheet shows the two rows as
`Ch8 Ch6 Ch4 Ch2 Gnd` and `Ch7 Ch5 Ch3 Ch1 10v`, which pairs exactly as the
v2.5 sources do — but a printed pin map does not tell you which way round the
connector sits on your board. That is what Step 2 above is for.

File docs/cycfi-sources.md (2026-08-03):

# What Cycfi's files actually say

A record, not a specification. Where this and [`DESIGN.md`](DESIGN.md)
differ, `DESIGN.md` is right — but nothing here should differ, because
`design.py` asserts the pin maps below at import and the build fails if they
drift.

The pin maps below were read out of Cycfi's own Eagle sources — not from their
forum, not from a photograph of a board. The one exception is the v2.6.1
cross-check, which comes from their published datasheet and is labelled as
such.

| | |
| --- | --- |
| Repository | <https://github.com/cycfi/nu> |
| Commit | `dc334a32f05ff16e0e7419b5c41f4c18d135e86d`, 2021-12-14 |
| Branch note | "Merge branch 'master' into version_2.5" |
| Files | `nu_capsule/nu_preamp.sch`, `internal_breakout/internal_breakout.sch`, and the matching `.brd` for connector geometry |
| Format | Eagle 6.3 XML, parsed with `xml.etree` |
| Licence | CC BY-NC 4.0 — their schematics, quoted here for interoperability |

The breakout silkscreen in this commit reads **INTERNAL BREAKOUT V2.5**. The
hub targets a v2.6 breakout, for which Cycfi have not published Eagle files —
but they have published a datasheet, and it corroborates the pin map. See
[v2.6.1, cross-checked](#v261-cross-checked) at the end.

## v2.6.1, cross-checked

Second source: **<https://www.cycfi.com/assets/Internal-Breakout-2.6.pdf>**,
"Internal Breakout v2.6.1", 11 pages. Not schematics — a pinout datasheet. Its
page 3 diagram labels the two rows of the Nu Multi Ch 1-8 connector:

    Ch8  Ch6  Ch4  Ch2  Gnd
    Ch7  Ch5  Ch3  Ch1  10v

and the Ch 7-14 connector beside it:

    Ch14 Ch12 Ch10 Ch8  Gnd
    Ch13 Ch11 Ch9  Ch7  10v

Read as column pairs, that is CH7/CH8, CH5/CH6, CH3/CH4, CH1/CH2, supply/GND
— **identical to the v2.5 J3 table below**, including the CH7/CH8 overlap
between the two connectors. The hub's pin map holds across the revision.

Two differences worth recording:

- The supply pin is labelled **10V** on 2.6.1, where the v2.5 schematic calls
  the net `V+` and feeds it from the `PWR SELECT` jumper. Measure it rather
  than assuming which.
- The v2.6 board is physically redesigned — Cycfi list it as 27 × 38 mm
  against the 50 × 35 mm outline in the Eagle files — so the connector's
  orientation on the board is not carried over from what is drawn here.

The rest of this document is the v2.5 Eagle extraction, unchanged.

## The capsule — `nu_capsule/nu_preamp.sch`

Two connectors, and they are at opposite ends of the capsule PCB.

### H2, power — Eagle package `3P-2MM-TH`, library `CYCFI_Con`

Three pads at −2 / 0 / +2 mm, 0.75 mm drill, so 2.00 mm pitch.

| Pin | Net | Why |
| --- | --- | --- |
| 1 | `N$19` | Goes to `D1.A`. `D1` is a `D_SCHOTTKY` whose cathode is `VCC1`, so **pin 1 is V+ and the capsule protects itself against reverse polarity**. |
| 2 | `GND` | |
| 3 | `GND` | Both, not one. |

### H1, signal — Eagle package `2P-2MM-TH`, library `CYCFI_Con`

Two pads at −1 / +1 mm, 0.75 mm drill.

| Pin | Net | Why |
| --- | --- | --- |
| 1 | `N$1` | `C3.2` and `R2.2`. `C3` is 10 µF from `U1.OUT` (a TLV170), `R2` is 10 k to ground. So **pin 1 is the coupled output**. |
| 2 | `GND` | |

### The capsule decouples itself

    VCC1 : C1.1, C2.2, D1.C, R13.2, R15.2, R7.1, R8.2, R9.2, U1.V+
    GND  : C1.2, C2.1, ...

`C1` is `0.1uF` and `C2` is `4.7uF`, both across `VCC1`/`GND`, on the capsule.
This is the whole reason the hub carries no components.

## The breakout — `internal_breakout/internal_breakout.sch`

### J3 — silk `NU MULTI INPUT 1`, Eagle package `2X5`, library `headers(2mm)`

Pads at x ∈ {−4, −2, 0, 2, 4} and y ∈ {−1, +1}, 0.75 mm drill: **2.00 mm
pitch on both axes, numbered in pairs across the two rows.**

| Pin | Net | | Pin | Net |
| --- | --- | --- | --- | --- |
| 1 | CH7 | | 2 | CH8 |
| 3 | CH5 | | 4 | CH6 |
| 5 | CH3 | | 6 | CH4 |
| 7 | CH1 | | 8 | CH2 |
| 9 | V+ | | 10 | GND |

Three things follow, and all three shaped the hub:

**CH7 and CH8 are shared with J4.** The extracted nets are

    CH7 : J10.8, J15.3, J17.3, J3.1, J4.7
    CH8 : J10.7, J16.3, J17.1, J3.2, J4.8

so J3 pins 1–2 are the same two nets as J4 pins 7–8 — the second Nu Multi
input. Driving them from the hub would contend with anything plugged in there.

**J3 is on the underside.** Its Eagle placement is `rot="MR270"`; the `MR`
prefix is a mirrored element, which in Eagle means the bottom layer. So are
J4, J10 and J11. Electrically irrelevant, but it is why the two ends of the
cable do not look alike once they are in the instrument.

**V+ is not a fixed rail.** `J14` is a 3-pin header silkscreened `PWR SELECT`:

    VCC   : ... J13.3, J14.1, U1.ON/OFF, U1.VIN     (unregulated in)
    V+    : J1.1, J14.2, J15.1, ... J3.9, J4.9      (what J3 pin 9 carries)
    +10VA : C2.1, C3.1, C5.1, C6.1, J12.3, J14.3, U1.VOUT   (LP2985 out)

Whatever that jumper selects is what arrives at the hub, and the hub passes it
straight to six capsules. The board does not care; the capsules and the person
setting the jumper do.

### J4 — silk `NU MULTI INPUT 2`

Same package, carrying CH7–CH14, with pins 7–8 overlapping J3's pins 1–2 as
above. The hub does not use it. A second hub on J4 would give channels 9–14
and would need its own pin map, since J4's numbering is not J3's.

## Reproducing this

The tables above came from parsing the Eagle XML directly:

```bash
git clone --depth 1 https://github.com/cycfi/nu.git
python3 - <<'EOF'
import xml.etree.ElementTree as ET
for f in ['nu/nu_capsule/nu_preamp.sch',
          'nu/internal_breakout/internal_breakout.sch']:
    root = ET.parse(f).getroot()
    print(f)
    for net in root.find('.//sheets/sheet').findall('.//nets/net'):
        pins = sorted(f"{r.get('part')}.{r.get('pin')}"
                      for s in net.findall('segment')
                      for r in s.findall('pinref'))
        print(f"  {net.get('name'):8} : {', '.join(pins)}")
EOF
```

Swap `nets/net` for `elements/element` in the `.brd` files to get the
placements and rotations, and `packages/package` for the pad geometry.

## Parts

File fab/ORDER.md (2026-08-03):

# Ordering the Cycfi Nu hub

Upload `cycfi-nu-hub-pcbway.zip`. It holds the gerbers, the Excellon drill file
and this document, and it is only written when DRC is clean, so a board with
known errors cannot reach a fab from this repository by accident.

This is about as easy a board as gets made: two layers, no components, nothing
finer than a 0.30 mm track. Every stock process at every low-cost fab covers
it. What follows is the handful of things the gerbers do not say.

## The board

| | |
| --- | --- |
| **Layers** | **2**, 1 oz copper |
| **Board size** | **61.0 × 24.0 mm**, rectangular |
| Thickness | 1.6 mm |
| Soldermask | any colour |
| Silkscreen | white, top only — the bottom carries nothing |
| Surface finish | lead-free HASL is fine |
| Quantity | whatever the minimum is; you want one |

## The four things that are not in the gerbers

**1. The four mounting holes must not be plated.** They are 2.70 mm M2.5
clearance holes at the corners and they are deliberately off the ground net.
A hub screwed into a shielded cavity with metal screws and *plated* holes
would bond the audio ground to the cavity foil through the mounting hardware,
in parallel with the cable — a second ground path, which is the loop the
single-point pad at E1 exists to avoid. The drill file marks them NPTH. Some
fabs merge PTH and NPTH by default; do not let this one.

**2. Nothing is fitted.** This is a bare-board order. The board carries no
components at all, by design — see `docs/DESIGN.md`. The parts list below is for
whoever builds the instrument, not for the fab.

**3. Route to the outline, no panel tabs inside it.** It is a plain rectangle
and there is copper 0.50 mm from every edge.

**4. Both layers are poured.** The large ground areas on F.Cu and B.Cu are
intentional and are not floods left over from routing.

## Holes

40 header holes at 0.80 mm, 1 pad hole at 1.00 mm and 6 vias at 0.40 mm, so
47 plated holes in total. Plus 4 unplated holes at 2.70 mm for mounting.

**18 placements**, all through-hole, none of them fitted at the fab.

## Design rules

Every number here comes from `rules.py`, which is also what `gen_project.py`
writes into the KiCad project for DRC to enforce, so the board was laid out to
exactly these and checked against exactly these.

| | |
| --- | --- |
| Min track width | 0.30 mm |
| Power track width | 0.60 mm |
| Min clearance | 0.25 mm |
| Min drill | 0.40 mm |
| Min annular ring | 0.20 mm |
| Via pad / drill | 0.80 / 0.40 mm |
| Board edge clearance | 0.50 mm |

The annular ring is the only figure with real arithmetic behind it: a
fabricator's cumulative drill and registration error runs to about 0.003"
(0.076 mm), which leaves 0.124 mm of ring in the worst case against an
IPC-2221 Class 2 minimum of 0.05 mm.

## What to buy alongside it

Headers, all **2.00 mm pitch vertical male**, to match the Nu capsules' own
H1/H2 and the breakout's J3:

| Qty | Part | Where |
| --- | --- | --- |
| 1 | 2×5 way | J1, to the Internal Breakout |
| 6 | 1×3 way | P1–P6, capsule power |
| 6 | 1×2 way | S1–S6, capsule signal |

A single 2.00 mm male header strip snapped to length covers all three; you
need 40 pins of it plus the 2×5.

Also 4 × M2.5 screws and standoffs, and — if you want it — a short length of
wire for E1.

### Cable

Everything on the board mates with **2.00 mm female crimp housings** on
0.50 mm square posts. [`docs/CABLES.md`](../docs/CABLES.md) has the part
numbers, suppliers and a position table for every cable; what follows is just
the shape of the job.

Do not expect one crimp terminal to cover the whole loom. The twelve
single-row cables use Hirose's A4B/A3B system, the same parts Cycfi specify
for the capsules — but 2.00 mm *dual-row* is a fragmented standard and the
2×5 needs its own housing and contact. The hub's `J1` and the breakout's `J3`
are deliberately the same interface, so whichever housing you settle on is
used at both ends of that cable.

| Cable | Housings | Positions each |
| --- | --- | --- |
| Hub → breakout, ×1 | 2 × 10-way (2×5) | 8 of 10 populated |
| Capsule power, ×6 | 2 × 3-way | 3 |
| Capsule signal, ×6 | 2 × 2-way | 2 |

That is 76 crimp terminals in total, and it is worth buying half as many
again: the first few are practice.

**The hub → breakout cable is wired straight through, position n to position
n, with positions 1 and 2 left empty at both ends.** Nothing crosses in it.
`docs/DESIGN.md` has the pin table and explains why the two empty positions are
also what makes a reversed cable harmless.

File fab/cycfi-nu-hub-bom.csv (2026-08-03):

Reference | Value | Footprint | QUANTITY | Description
E1 | SHIELD/GND | TestPoint:TestPoint_THTPad_2.0x2.0mm_Drill1.0mm | 1 | Solder pad to GND: trunk cable screen, cavity foil, optionally bridge earth
H1-H4 | M2.5 | MountingHole:MountingHole_2.7mm_M2.5 | 4 | M2.5 clearance hole, unplated
J1 | TO BREAKOUT J3 | Connector_PinHeader_2.00mm:PinHeader_2x05_P2.00mm_Vertical | 1 | 2x5 2.00mm to Internal Breakout J3 (NU MULTI INPUT 1); pins 1-2 not fitted
P1 | CH1 PWR | Connector_PinHeader_2.00mm:PinHeader_1x03_P2.00mm_Vertical | 1 | Capsule 1, low E (6th) -- power, to capsule H2: 1=V+, 2=GND, 3=GND
P2 | CH2 PWR | Connector_PinHeader_2.00mm:PinHeader_1x03_P2.00mm_Vertical | 1 | Capsule 2, A (5th) -- power, to capsule H2: 1=V+, 2=GND, 3=GND
P3 | CH3 PWR | Connector_PinHeader_2.00mm:PinHeader_1x03_P2.00mm_Vertical | 1 | Capsule 3, D (4th) -- power, to capsule H2: 1=V+, 2=GND, 3=GND
P4 | CH4 PWR | Connector_PinHeader_2.00mm:PinHeader_1x03_P2.00mm_Vertical | 1 | Capsule 4, G (3rd) -- power, to capsule H2: 1=V+, 2=GND, 3=GND
P5 | CH5 PWR | Connector_PinHeader_2.00mm:PinHeader_1x03_P2.00mm_Vertical | 1 | Capsule 5, B (2nd) -- power, to capsule H2: 1=V+, 2=GND, 3=GND
P6 | CH6 PWR | Connector_PinHeader_2.00mm:PinHeader_1x03_P2.00mm_Vertical | 1 | Capsule 6, high E (1st) -- power, to capsule H2: 1=V+, 2=GND, 3=GND
S1 | CH1 SIG | Connector_PinHeader_2.00mm:PinHeader_1x02_P2.00mm_Vertical | 1 | Capsule 1, low E (6th) -- signal, to capsule H1: 1=OUT, 2=GND
S2 | CH2 SIG | Connector_PinHeader_2.00mm:PinHeader_1x02_P2.00mm_Vertical | 1 | Capsule 2, A (5th) -- signal, to capsule H1: 1=OUT, 2=GND
S3 | CH3 SIG | Connector_PinHeader_2.00mm:PinHeader_1x02_P2.00mm_Vertical | 1 | Capsule 3, D (4th) -- signal, to capsule H1: 1=OUT, 2=GND
S4 | CH4 SIG | Connector_PinHeader_2.00mm:PinHeader_1x02_P2.00mm_Vertical | 1 | Capsule 4, G (3rd) -- signal, to capsule H1: 1=OUT, 2=GND
S5 | CH5 SIG | Connector_PinHeader_2.00mm:PinHeader_1x02_P2.00mm_Vertical | 1 | Capsule 5, B (2nd) -- signal, to capsule H1: 1=OUT, 2=GND
S6 | CH6 SIG | Connector_PinHeader_2.00mm:PinHeader_1x02_P2.00mm_Vertical | 1 | Capsule 6, high E (1st) -- signal, to capsule H1: 1=OUT, 2=GND

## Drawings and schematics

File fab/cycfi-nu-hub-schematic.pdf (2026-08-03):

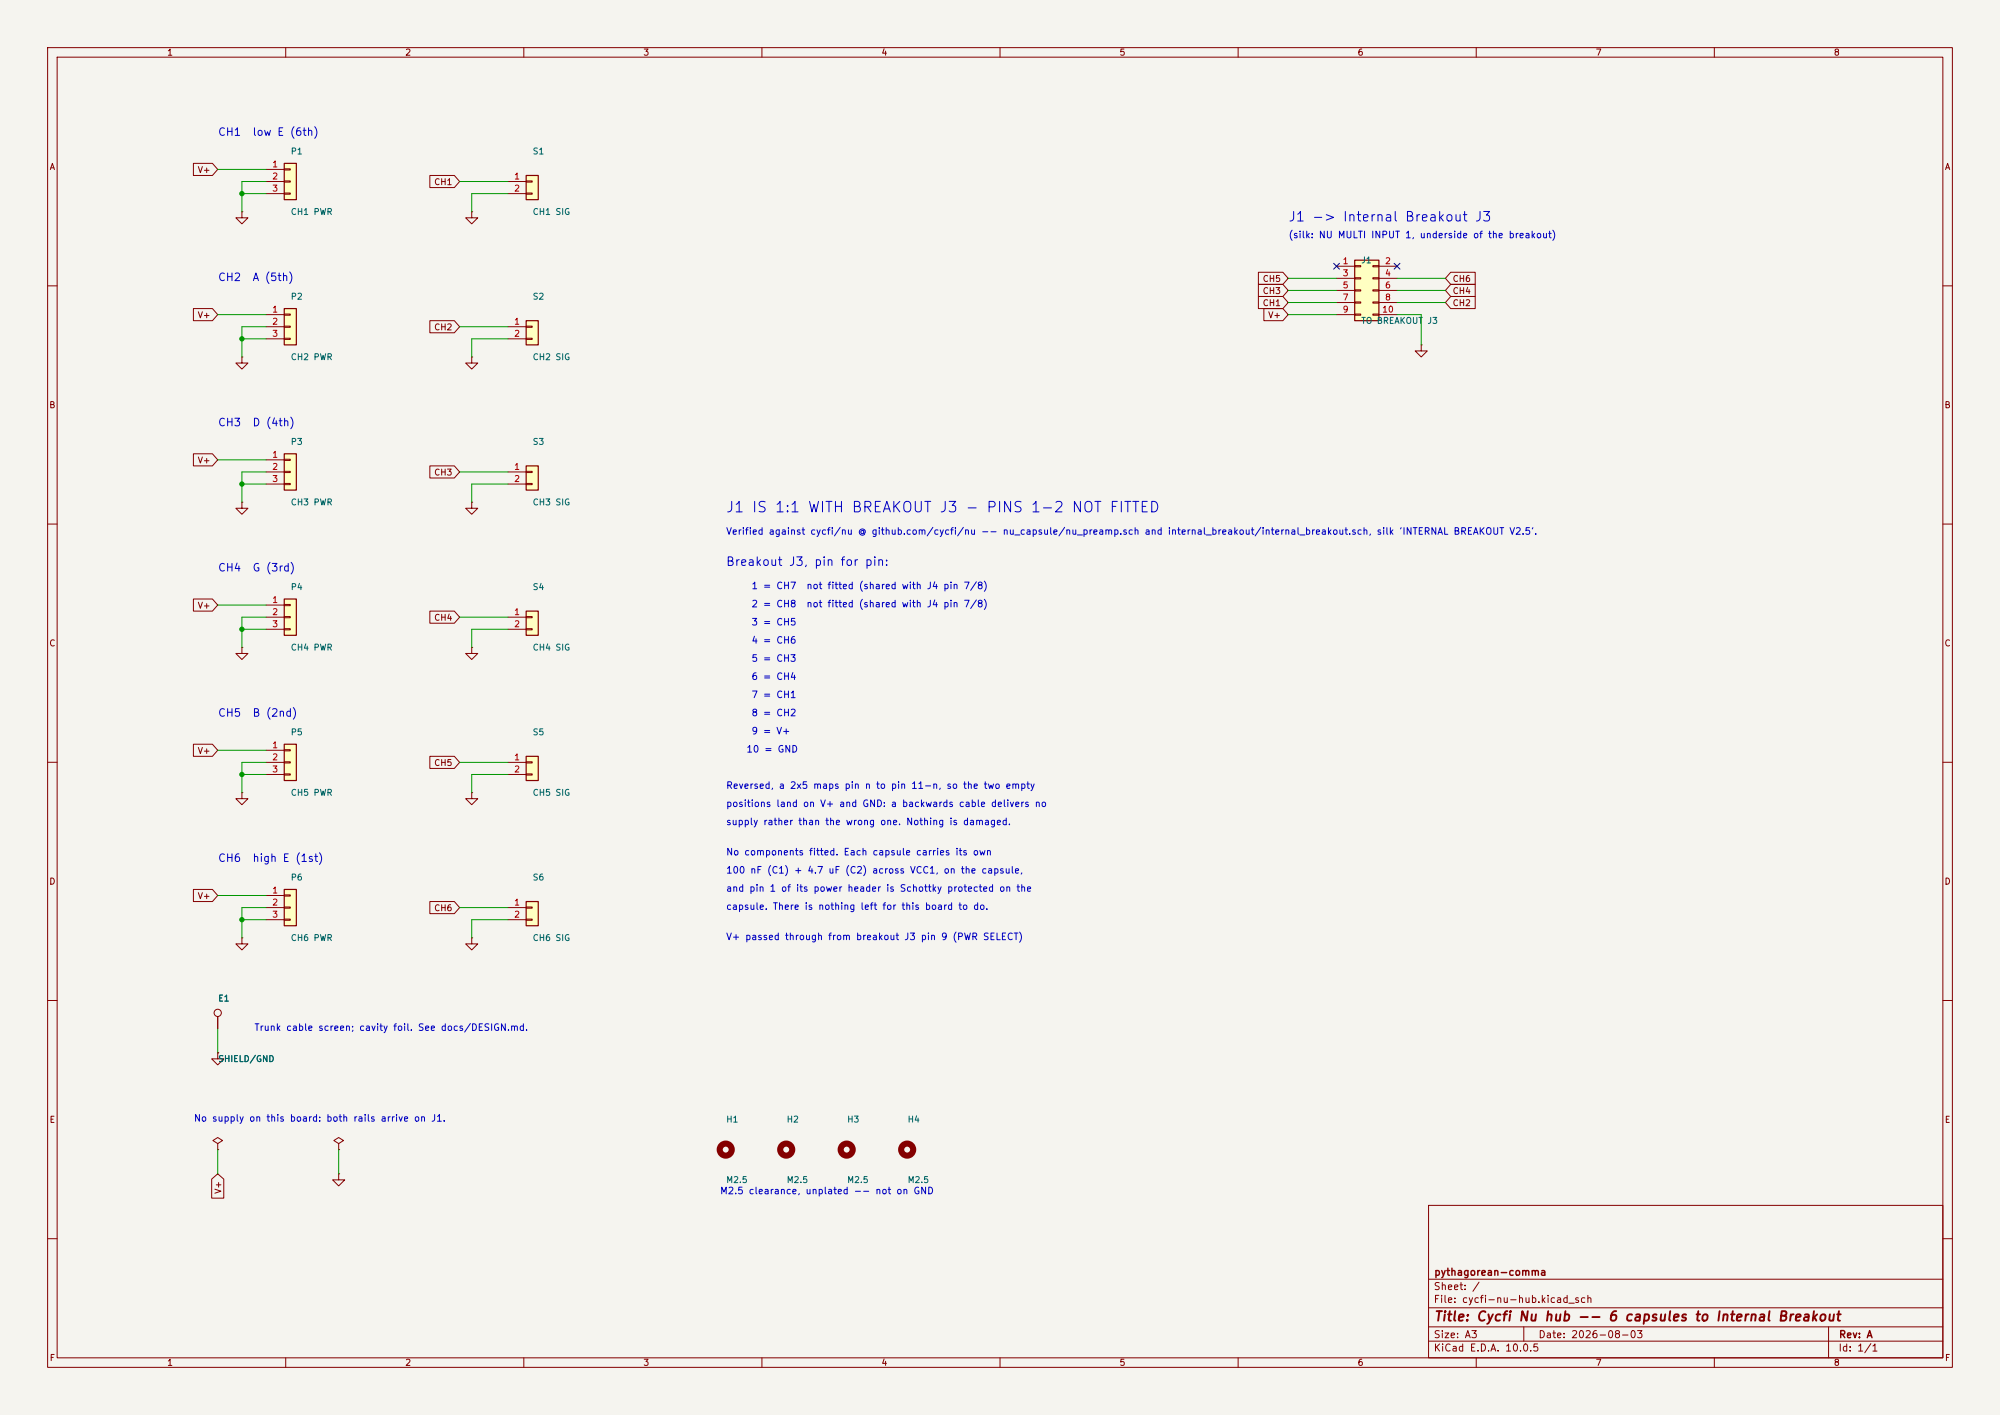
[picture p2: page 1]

J1 -> Internal Breakout J3
(silk: NU MULTI INPUT 1, underside of the breakout)

J1 IS 1:1 WITH BREAKOUT J3 - PINS 1-2 NOT FITTED

Verified against cycfi/nu @ github.com/cycfi/nu -- nu_capsule/nu_preamp.sch and internal_breakout/internal_breakout.sch, silk 'INTERNAL BREAKOUT V2.5'. Reversed, a 2x5 maps pin n to pin 11-n, so the two empty and pin 1 of its power header is Schottky protected on the No components fitted. Each capsule carries its own 10 = GND

Breakout J3, pin for pin:

2 = CH8 not fitted (shared with J4 pin 7/8) Trunk cable screen; cavity foil. See docs/DESIGN.md.

1 = CH7 not fitted (shared with J4 pin 7/8)

positions land on V+ and GND: a backwards cable delivers no
supply rather than the wrong one. Nothing is damaged.

100 nF (C1) + 4.7 uF (C2) across VCC1, on the capsule,

capsule. There is nothing left for this board to do. E1

V+ passed through from breakout J3 pin 9 (PWR SELECT) M2.5 clearance, unplated -- not on GND

No supply on this board: both rails arrive on J1.

pythagorean-comma
Sheet: /
File: cycfi-nu-hub.kicad_sch
Title: Cycfi Nu hub -- 6 capsules to Internal Breakout

Size: A3 | Rev: A | F Date: 2026-08-03
KiCad E.D.A. 10.0.5 | Id: 1/1

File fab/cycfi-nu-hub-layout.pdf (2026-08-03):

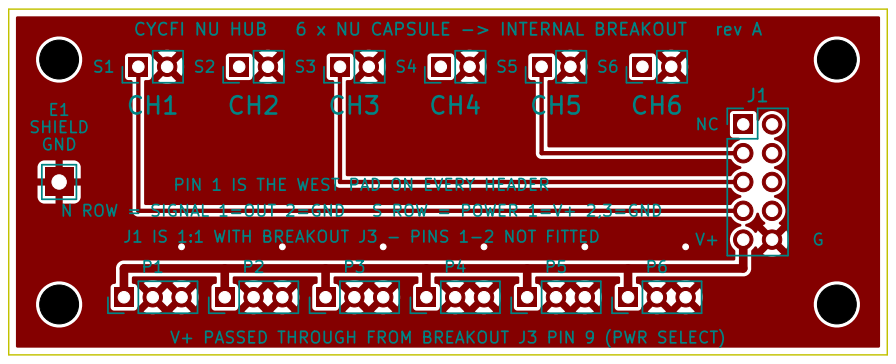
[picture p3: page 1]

PIN 1 IS THE WEST PAD ON EVERY HEADER

J1 IS 1:1 WITH BREAKOUT J3 - PINS 1-2 NOT FITTED

V+ PASSED THROUGH FROM BREAKOUT J3 PIN 9 (PWR SELECT)

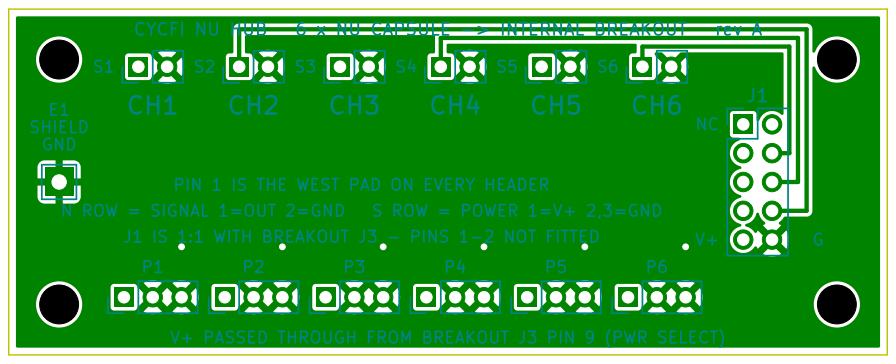
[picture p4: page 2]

PIN 1 IS THE WEST PAD ON EVERY HEADER

J1 IS 1:1 WITH BREAKOUT J3 - PINS 1-2 NOT FITTED

V+ PASSED THROUGH FROM BREAKOUT J3 PIN 9 (PWR SELECT)

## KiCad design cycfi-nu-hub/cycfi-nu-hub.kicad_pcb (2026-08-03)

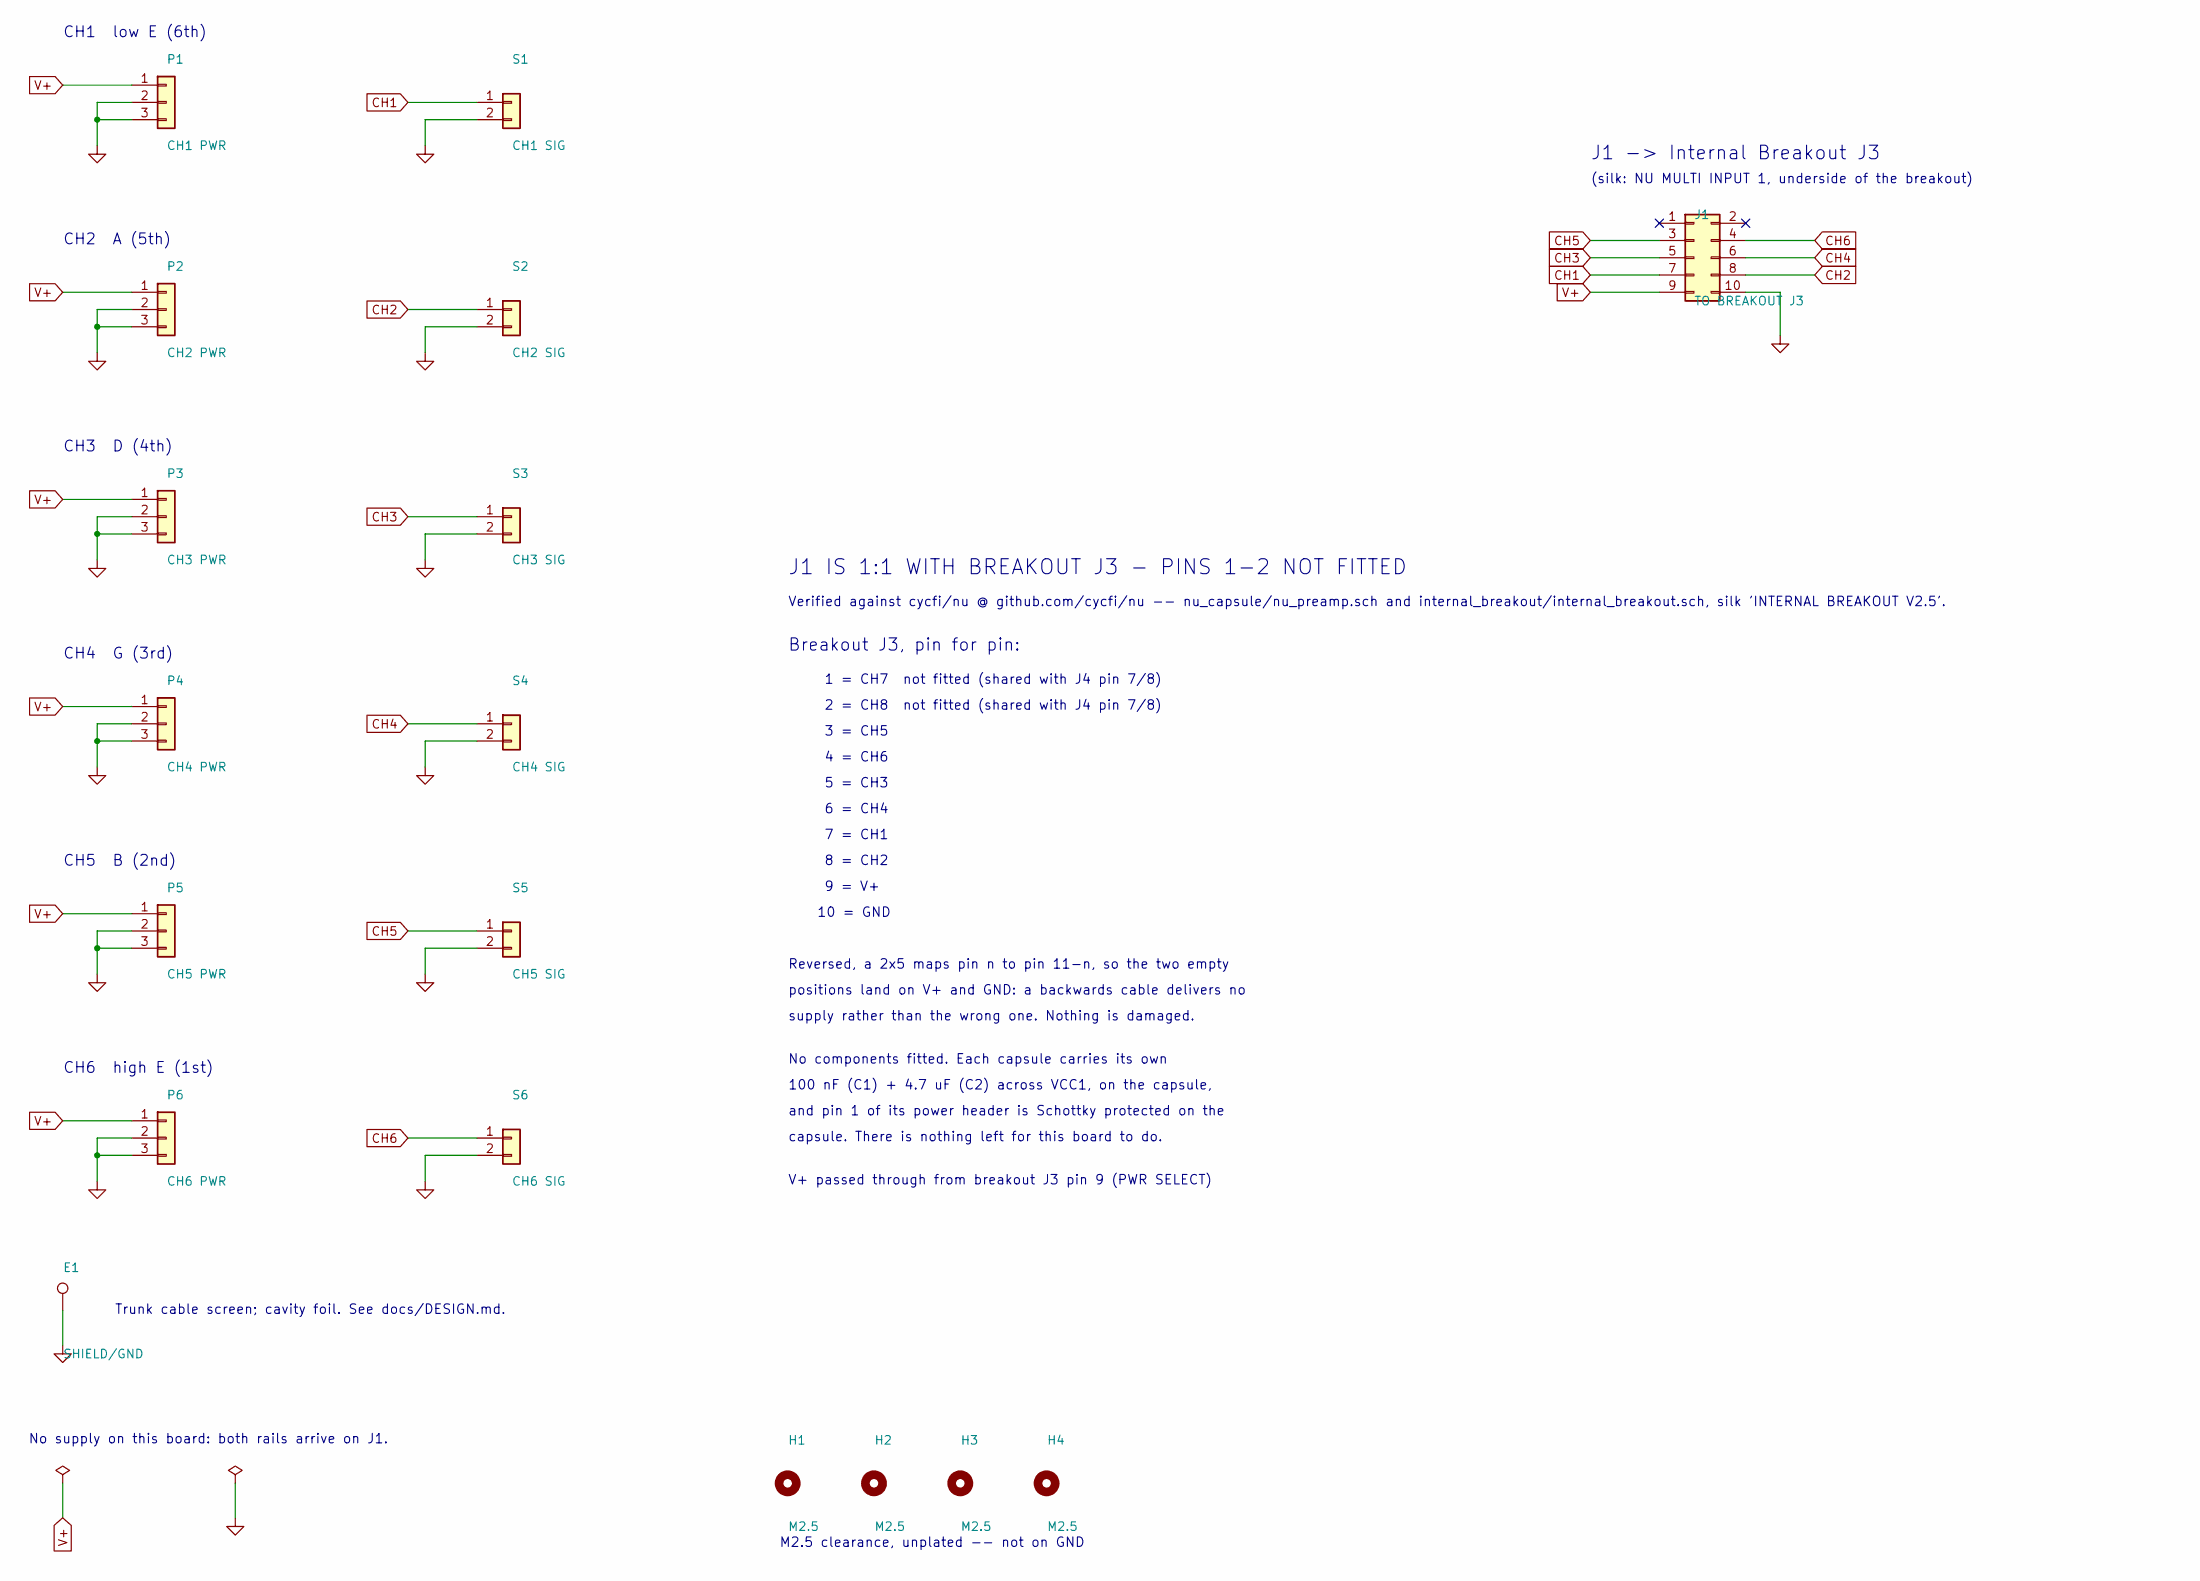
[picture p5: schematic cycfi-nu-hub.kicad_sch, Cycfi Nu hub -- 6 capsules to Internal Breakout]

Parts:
E1: SHIELD/GND; TestPoint_THTPad_2.0x2.0mm_Drill1.0mm
H1, H2, H3, H4: M2.5; MountingHole_2.7mm_M2.5
J1: TO BREAKOUT J3; PinHeader_2x05_P2.00mm_Vertical
P1: CH1 PWR; PinHeader_1x03_P2.00mm_Vertical
P2: CH2 PWR; PinHeader_1x03_P2.00mm_Vertical
P3: CH3 PWR; PinHeader_1x03_P2.00mm_Vertical
P4: CH4 PWR; PinHeader_1x03_P2.00mm_Vertical
P5: CH5 PWR; PinHeader_1x03_P2.00mm_Vertical
P6: CH6 PWR; PinHeader_1x03_P2.00mm_Vertical
S1: CH1 SIG; PinHeader_1x02_P2.00mm_Vertical
S2: CH2 SIG; PinHeader_1x02_P2.00mm_Vertical
S3: CH3 SIG; PinHeader_1x02_P2.00mm_Vertical
S4: CH4 SIG; PinHeader_1x02_P2.00mm_Vertical
S5: CH5 SIG; PinHeader_1x02_P2.00mm_Vertical
S6: CH6 SIG; PinHeader_1x02_P2.00mm_Vertical

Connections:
CH1: J1.7, S1.1
CH2: J1.8, S2.1
CH3: J1.5, S3.1
CH4: J1.6, S4.1
CH5: J1.3, S5.1
CH6: J1.4, S6.1
GND: E1.1, J1.10, P1.2, P1.3, P2.2, P2.3, P3.2, P3.3, P4.2, P4.3, P5.2, P5.3, P6.2, P6.3, S1.2, S2.2, S3.2, S4.2, S5.2, S6.2
V+: J1.9, P1.1, P2.1, P3.1, P4.1, P5.1, P6.1

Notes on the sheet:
CH1 low E (6th)
CH2 A (5th)
CH3 D (4th)
CH4 G (3rd)
CH5 B (2nd)
CH6 high E (1st)
J1 -> Internal Breakout J3
(silk: NU MULTI INPUT 1, underside of the breakout)
Trunk cable screen; cavity foil. See docs/DESIGN.md.
M2.5 clearance, unplated -- not on GND
No supply on this board: both rails arrive on J1.
J1 IS 1:1 WITH BREAKOUT J3 - PINS 1-2 NOT FITTED
Verified against cycfi/nu @ github.com/cycfi/nu -- nu_capsule/nu_preamp.sch and internal_breakout/internal_breakout.sch, silk 'INTERNAL BREAKOUT V2.5'.
Breakout J3, pin for pin:
1 = CH7 not fitted (shared with J4 pin 7/8)
2 = CH8 not fitted (shared with J4 pin 7/8)
3 = CH5
4 = CH6
5 = CH3
6 = CH4
7 = CH1
8 = CH2
9 = V+
10 = GND
Reversed, a 2x5 maps pin n to pin 11-n, so the two empty
positions land on V+ and GND: a backwards cable delivers no
supply rather than the wrong one. Nothing is damaged.
No components fitted. Each capsule carries its own
100 nF (C1) + 4.7 uF (C2) across VCC1, on the capsule,
and pin 1 of its power header is Schottky protected on the
capsule. There is nothing left for this board to do.
V+ passed through from breakout J3 pin 9 (PWR SELECT)

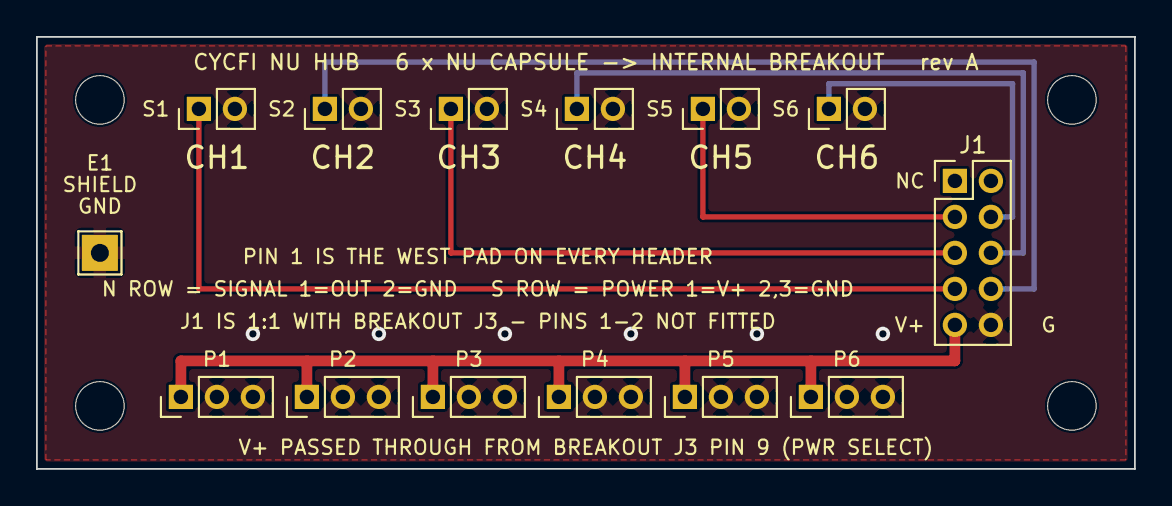
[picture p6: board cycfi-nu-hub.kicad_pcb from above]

Board: 2 copper layers, 61.0 x 24.0 mm, 18 parts (0 on the bottom side), 8 nets.

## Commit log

2026-08-03 Initial commit of cycfi nu hub design
    [cycfi-nu-hub-bom.csv, cycfi-nu-hub.kicad_pcb, cycfi-nu-hub.kicad_sch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]
2026-08-03 Added instructions on how to make the cables
    [cycfi-nu-hub.kicad_pcb, cycfi-nu-hub.kicad_sch]
2026-08-03 Updated the info around cables
2026-08-03 Clarified E1 shield
    [cycfi-nu-hub-bom.csv, cycfi-nu-hub.kicad_pcb, cycfi-nu-hub.kicad_sch]
2026-08-03 Generate geometry of part which can be used when fabricating an enclosure
    [cycfi-nu-hub.kicad_pcb]
